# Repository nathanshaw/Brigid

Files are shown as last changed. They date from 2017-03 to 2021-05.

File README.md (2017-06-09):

Machine Orchesta
# Brigid
Solenoid Driver

Please note that for each board you much change the ARDUINO_ID to a unique number

If you want to turn off LED feedback change LED_FEEDBACK to 0

If you don't want the startup sequence change BOOT_TEST to 0

If the LED is not yellow during the BOOT_TEST change your led pins until it is.

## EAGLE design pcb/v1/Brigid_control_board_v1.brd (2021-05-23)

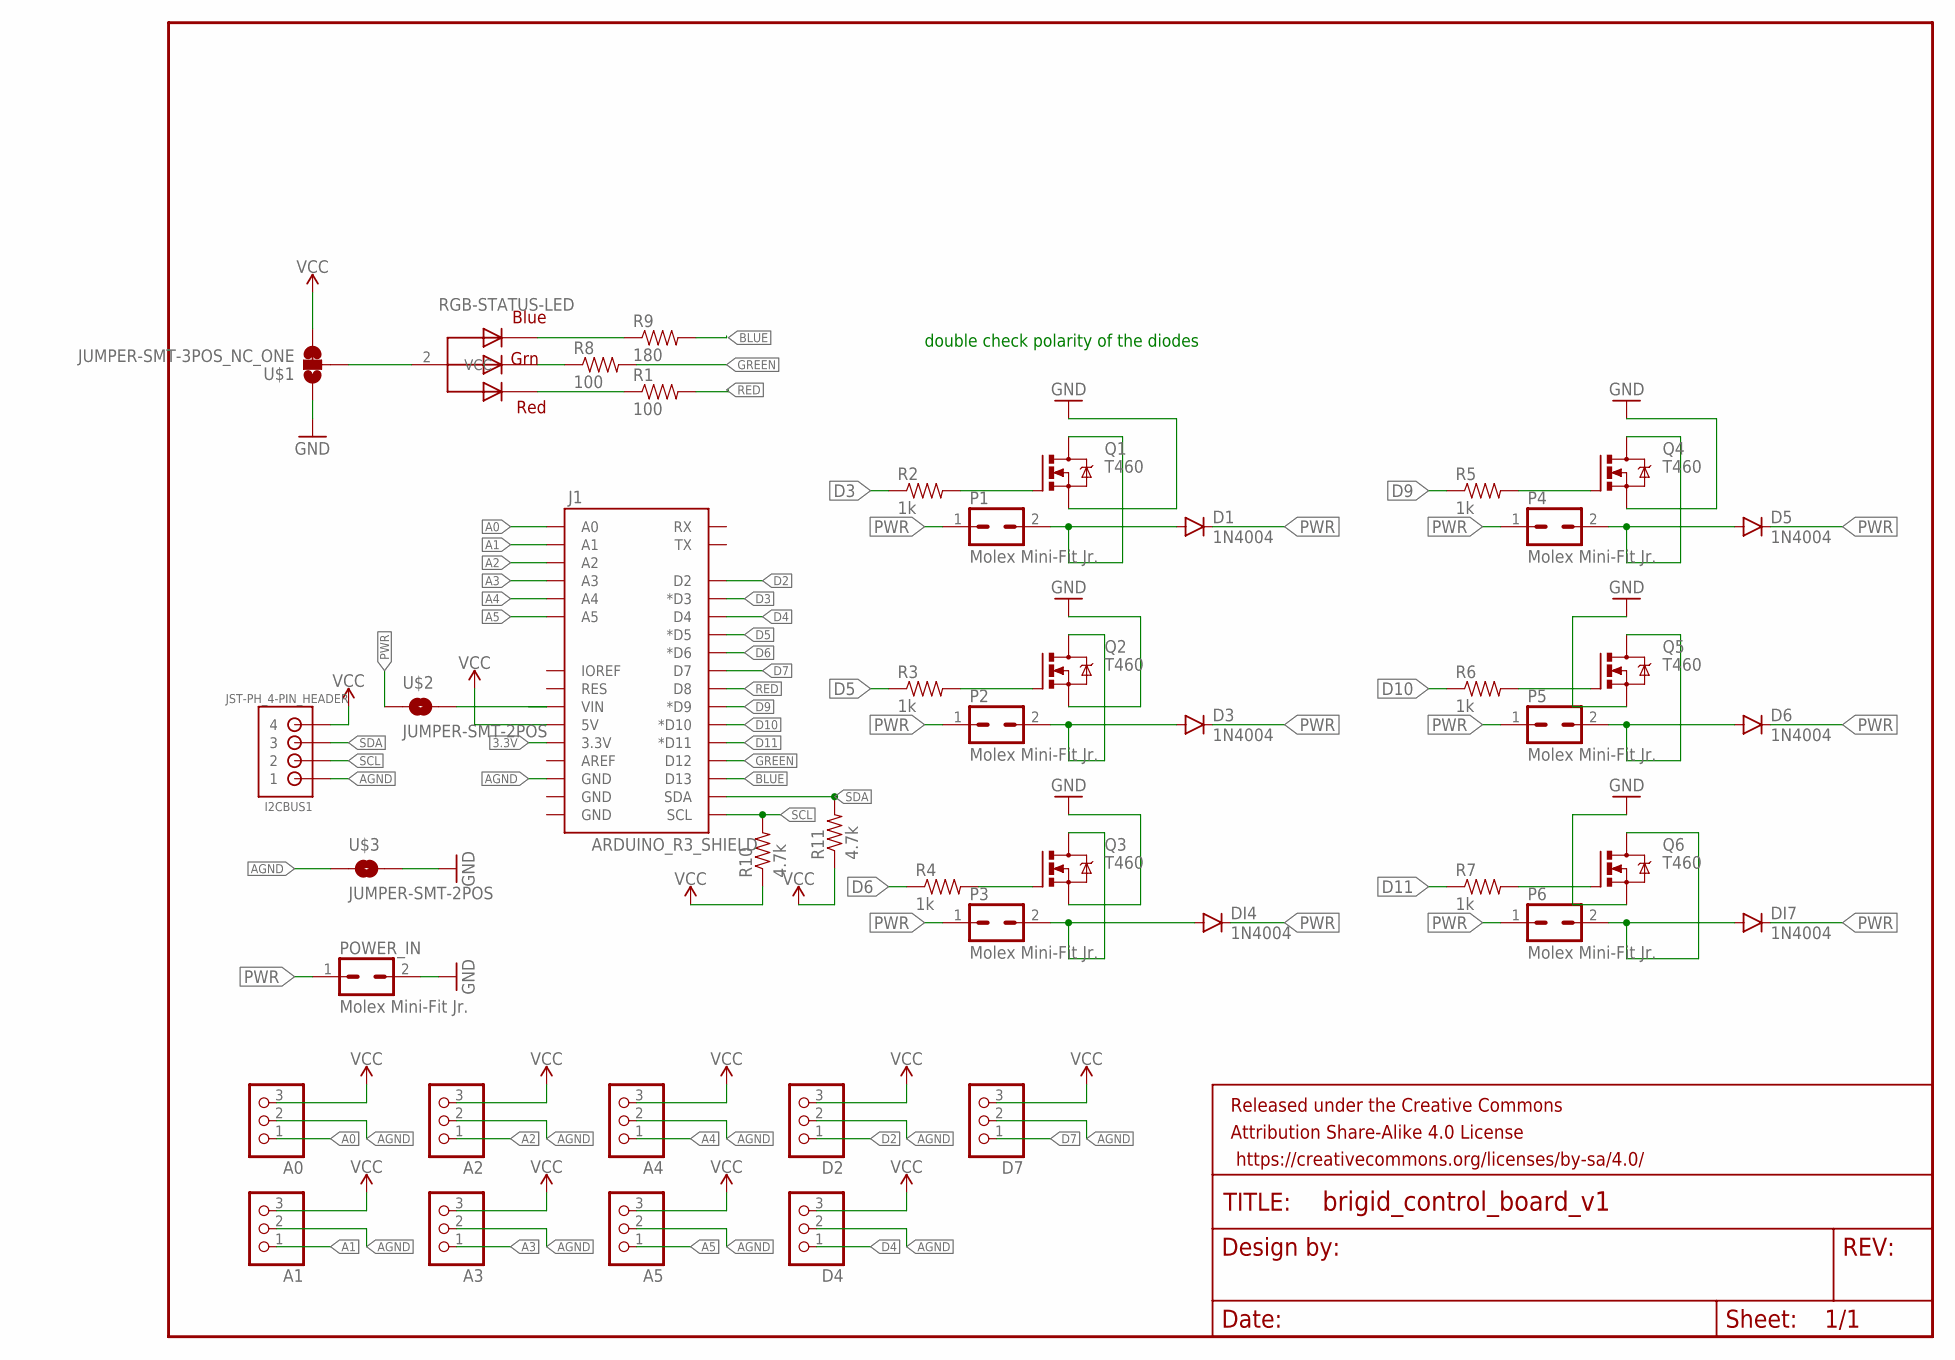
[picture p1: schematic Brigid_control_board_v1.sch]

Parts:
A0, A1, A2, A3, A4, A5: PINHD-1X3; 1X03
D1, D3, D5, D6: 1N4004; DIODE-1N4001
D2, D4, D7: PINHD-1X3; 1X03
DI4, DI7: 1N4004; DIODE-1N4001
FRAME1: FRAME-LETTER; CREATIVE_COMMONS
I2CBUS1: JST-PH_4-PIN_HEADER; JST_B4B-PH_HEADER
J1: ARDUINO_R3_SHIELD; UNO_R3_SHIELD
P1, P2, P3, P4, P5, P6: Molex Mini-Fit Jr.; 39-30-?02?
POWER_IN: Molex Mini-Fit Jr.; 39-30-?02?
Q1, Q2, Q3, Q4, Q5, Q6: T460; TO220BV
R1, R8: 100; AXIAL-0.3EZ
R2, R3, R4, R5, R6, R7: 1k; AXIAL-0.3EZ
R9: 180; AXIAL-0.3EZ
R10, R11: 4.7k; AXIAL-0.3EZ
RGB-STATUS-LED: RGB LED; LED5MMRGB
U$1: JUMPER-SMT-3POS_NC_ONE; SMT-JUMPER_3_1-NC_TRACE_NO-SILK
U$2, U$3: JUMPER-SMT-2POS; SMT-JUMPER_2_NO_NO-SILK

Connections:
3.3V: J1.3.3V
A0: A0.1, J1.A0
A1: A1.1, J1.A1
A2: A2.1, J1.A2
A3: A3.1, J1.A3
A4: A4.1, J1.A4
A5: A5.1, J1.A5
AGND: A0.2, A1.2, A2.2, A3.2, A4.2, A5.2, D2.2, D4.2, D7.2, I2CBUS1.P1 (1), J1.GND@2 (GND), U$3.1
BLUE: J1.D13, R9.P$2 (2)
D2: D2.1, J1.D2
D3: J1.D3 (*D3), R2.P$1 (1)
D4: D4.1, J1.D4
D5: J1.D5 (*D5), R3.P$1 (1)
D6: J1.D6 (*D6), R4.P$1 (1)
D7: D7.1, J1.D7
D9: J1.D9 (*D9), R5.P$1 (1)
D10: J1.D10 (*D10), R6.P$1 (1)
D11: J1.D11 (*D11), R7.P$1 (1)
GND: POWER_IN.2, Q1.S, Q2.S, Q3.S, Q4.S, Q5.S, Q6.S, U$1.1, U$3.2
GREEN: J1.D12, R8.P$2 (2)
unnamed: D1.A, P1.2, Q1.D
unnamed: R9.P$1 (1), RGB-STATUS-LED.4 (BLUE)
unnamed: RGB-STATUS-LED.2 (VCC), U$1.2
unnamed: R1.P$1 (1), RGB-STATUS-LED.1 (RED)
unnamed: R8.P$1 (1), RGB-STATUS-LED.3 (GREEN)
unnamed: Q2.G, R3.P$2 (2)
unnamed: D3.A, P2.2, Q2.D
unnamed: Q1.G, R2.P$2 (2)
unnamed: Q3.G, R4.P$2 (2)
unnamed: DI4.A, P3.2, Q3.D
unnamed: Q4.G, R5.P$2 (2)
unnamed: D5.A, P4.2, Q4.D
unnamed: Q5.G, R6.P$2 (2)
unnamed: D6.A, P5.2, Q5.D
unnamed: Q6.G, R7.P$2 (2)
unnamed: DI7.A, P6.2, Q6.D
PWR: D1.C, D3.C, D5.C, D6.C, DI4.C, DI7.C, P1.1, P2.1, P3.1, P4.1, P5.1, P6.1, POWER_IN.1, U$2.1
RED: J1.D8, R1.P$2 (2)
SCL: I2CBUS1.P2 (2), J1.SCL, R10.P$2 (2)
SDA: I2CBUS1.P3 (3), J1.SDA, R11.P$2 (2)
VCC: A0.3, A1.3, A2.3, A3.3, A4.3, A5.3, D2.3, D4.3, D7.3, I2CBUS1.P4 (4), J1.5V, R10.P$1 (1), R11.P$1 (1), U$1.3
VIN: J1.VIN, U$2.2

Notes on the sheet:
double check polarity of the diodes

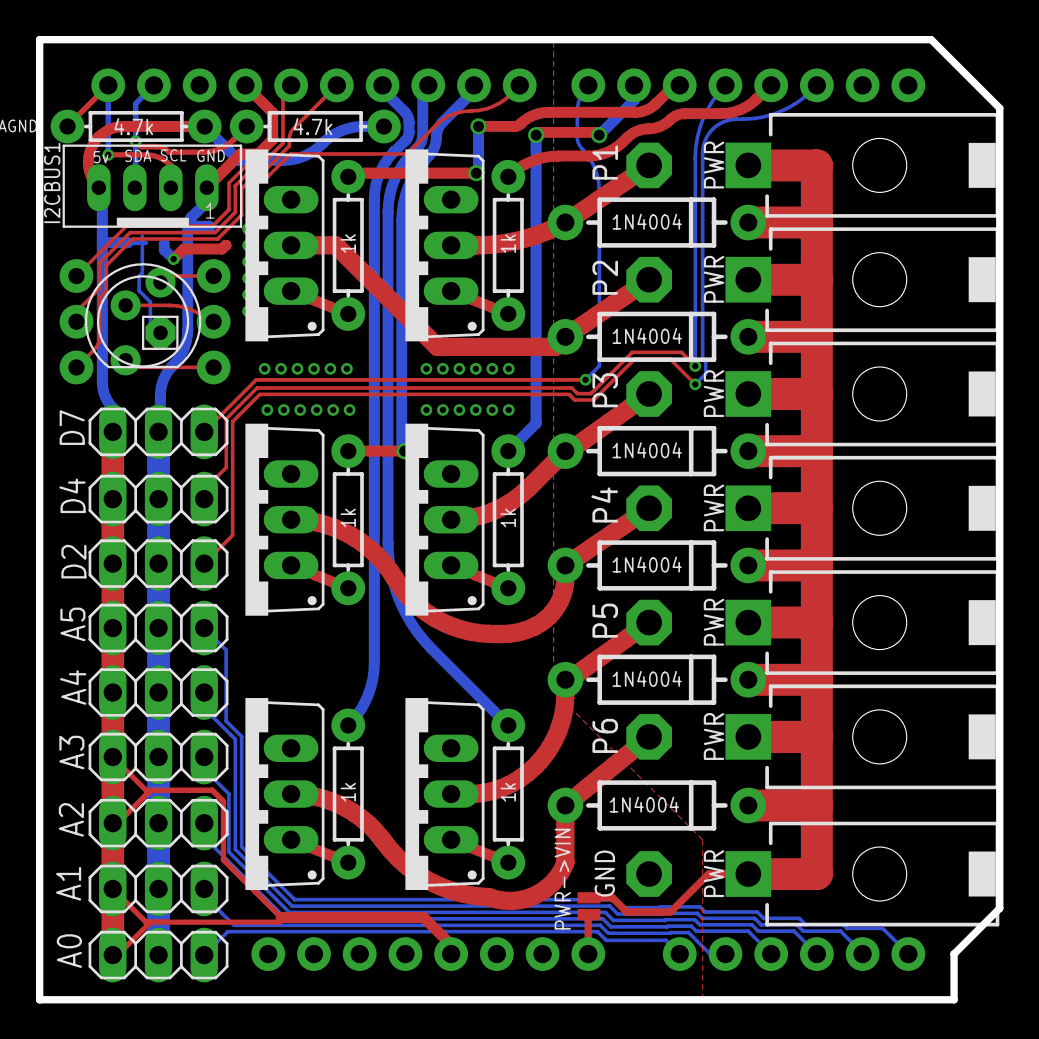
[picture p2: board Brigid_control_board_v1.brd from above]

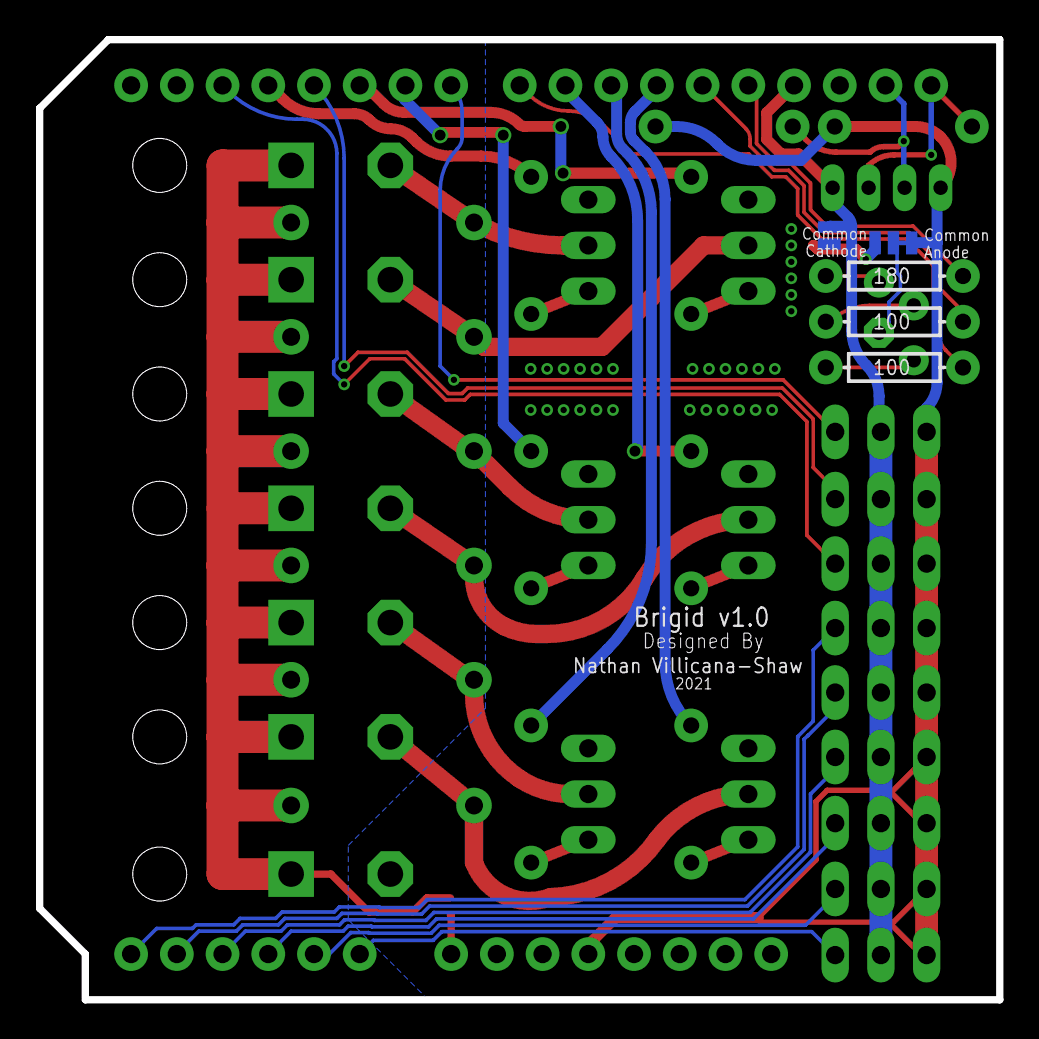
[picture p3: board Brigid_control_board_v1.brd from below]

Board: 2 copper layers, 53.3 x 53.3 mm, 46 parts (5 on the bottom side), 41 nets.

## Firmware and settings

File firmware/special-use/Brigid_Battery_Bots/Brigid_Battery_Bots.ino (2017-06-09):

// solenoids need to happen before the motors
// botnum/board type/board num

#define BOOT_TEST 1
#define LED_FEEDBACK 1
#define RED_LED A4
#define GREEN_LED A3
#define BLUE_LED A2
#define NUM_SOLENOIDS 4
#define NUM_LEDS 2
#define NUM_MOTORS 0

// actuator pins
int actuators[] = {
  3, 5, 6, 9, 10, 11
};

int motors[] = {
};

// just the solenoids
int solenoids[] = {
  3, 5, 6, 10
};
// just the leds
int leds[] = {
  11, 7
};

void setup() {
  Serial.begin(57600);
  // interrupt timer parameters
  pinMode(RED_LED, OUTPUT);
  pinMode(GREEN_LED, OUTPUT);
  pinMode(BLUE_LED, OUTPUT);
  digitalWrite(GREEN_LED, HIGH);
  digitalWrite(RED_LED, HIGH);
  digitalWrite(BLUE_LED, LOW);

  for (int i = 0; i < NUM_SOLENOIDS; i++) {
    pinMode(actuators[i], OUTPUT);
    digitalWrite(actuators[i], LOW);
  }
  for (int i = 0; i < NUM_LEDS; i++) {
    pinMode(leds[i], OUTPUT);
    digitalWrite(actuators[i], LOW);
  }
  for (int i = 0; i < NUM_MOTORS; i++) {
    pinMode(motors[i], OUTPUT);
    digitalWrite(actuators[i], LOW);
  }
  digitalWrite(GREEN_LED, LOW);
  digitalWrite(RED_LED, LOW); 
}

void allAtOnce(int delayTime){
  Serial.print("All at once : ");
  Serial.print(" : ");
  Serial.println(delayTime);
  // turn everything on at once
  for (int t = 0; t < 6; t++){
    digitalWrite(actuators[t], HIGH);
    delay(1);
  }
  delay(50);
  for (int t = 0; t < 6; t++){
    digitalWrite(actuators[t], LOW);
    delay(1);
  }
  delay(delayTime);
}

void cycleThrough(int delayTime){
  Serial.print("Cycle Through 2 ");
  Serial.print(" : ");
  Serial.println(delayTime);
  for (int i = int(delayTime*0.5); i > 2; i--) {
    for (int t = NUM_MOTORS; t < 6; t++){
      if (random() > 0.6){
        digitalWrite(actuators[t], HIGH);
        delay(i + random(10));
        digitalWrite(actuators[t], LOW);
        delay(delayTime - i);
      }
    } 
  } 
}

void allOff() {
  // turn everything off
  Serial.println("Turning everything off");
  for (int i; i < NUM_SOLENOIDS; i++) {
    digitalWrite(actuators[i], LOW);  
  } 
  for (int i; i < NUM_MOTORS; i++) {
    digitalWrite(actuators[NUM_SOLENOIDS + i], LOW);
  }
}

void slowRandomSolenoids1(int delayTime) {
  Serial.print("Slow random solenoids 1 ");
  Serial.print(" : ");
  Serial.println(delayTime);
  if (random() > 0.55){
    float theRandom = random();
    if (theRandom > 0.6 && NUM_SOLENOIDS > 3) {
      digitalWrite(actuators[0], HIGH);
    }
    else if(theRandom > 0.3 && NUM_SOLENOIDS > 1) {
      digitalWrite(actuators[1], HIGH);
    }
    else if(theRandom > 0.15 && NUM_SOLENOIDS > 2) {
      digitalWrite(actuators[2], HIGH);
    }
    else if(theRandom > 0 && NUM_SOLENOIDS > 3) {
      digitalWrite(actuators[3], HIGH);
    }
  }
  delay(40);
  allOff();
  delay(random(delayTime, delayTime*2)); 
}

void slowRandomSolenoids2(int delayTime) {
  Serial.print("Slow random solenoids 2 ");
  Serial.print(" : ");
  Serial.println(delayTime);
  if (random() > 0.55){
    float theRandom = random();
    if (theRandom > 0.6 && NUM_SOLENOIDS > 3) {
      solenoidHum(0, random(100,400));
    }
    else if(theRandom > 0.3 && NUM_SOLENOIDS > 1) {
      solenoidHum(1, random(100,400));
    }
    else if(theRandom > 0.15 && NUM_SOLENOIDS > 2) {
      solenoidHum(2, random(100,400));
    }
    else if(theRandom > 0 && NUM_SOLENOIDS > 3) {
      solenoidHum(3, random(100,400));
    }
  }
  delay(20);
  allOff();
  delay(random(delayTime*0.25, delayTime*2)); 
}

void pulseLights(int ledNum, int timeMS){
  Serial.print("Pulseing Lights ");
  Serial.print(ledNum);
  Serial.print(" : ");
  Serial.println(timeMS);
  float delayTime = timeMS / 512;
  for (int power = 0; power < 255; power++) {
    analogWrite(leds[ledNum], power); 
    delay(delayTime);
  }
  for (int power = 255; power > -1; power--) {
    analogWrite(leds[ledNum], power); 
    delay(delayTime);
  }
}

void solenoidHum(int solenoidNum, int timeMS){
  Serial.print("Pulseing solenoid ");
  Serial.print(solenoidNum);
  Serial.print(" : ");
  Serial.println(timeMS);
  float moddedTime = timeMS * (random() + 0.5);
  float delayTime = timeMS / 512;
  for (int power = 0; power < 255; power++) {
    analogWrite(solenoids[solenoidNum], power); 
    delay(delayTime);
  }
  delay(delayTime*10);
  for (int power = 255; power > -1; power--) {
    analogWrite(solenoids[solenoidNum], power); 
    delay(delayTime);
  }
}


void loop() {
  if(random(0, 100) < 2){
    for  (int l = 120; l >100; l = l - 3){
      cycleThrough(l);
    }
  }
  slowRandomSolenoids1(7000);
  if (random(0, 100) < 20) {
    pulseLights(0, random(2000, 10000));
  }
  solenoidHum(int(random(4)), random(100, 10000));
  if (random(0, 100) < 20) {
    pulseLights(0, random(2000, 10000));
  }
  slowRandomSolenoids2(7000);
}

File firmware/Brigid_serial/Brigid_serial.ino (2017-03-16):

#define NUM_SOLENOIDS 6
// botnum/board type/board num
#define BOT_ID 1
#define BOT_TYPE 1
#define ARDUINO_ID 4

// will trigger each solinoid during init
#define BOOT_TEST 1
// will flash LED's when board receives message
#define LED_FEEDBACK 1

#include <avr/interrupt.h>
#include <avr/io.h>

#define LED_POWER 12
#define LED_STATUS 13
#define RED_LED A4
#define GREEN_LED A3
#define BLUE_LED A2
// brigid is 12 and 13
// #define RED_LED 12
// #define GREEN_LED 13
// #define BLUE_LED 13

char bytes[2];
short notes[NUM_SOLENOIDS];

int handshake = 0;
int statustimer = 0;

// actuator pins
int actuators[] = {
  3, 5, 6, 9, 10, 11
};

void setup() {
  Serial.begin(57600);
  // interrupt timer parameters
  TCCR2A = 1;
  TCCR2B = 3;
  TIMSK2 = 1;
  pinMode(RED_LED, OUTPUT);
  pinMode(GREEN_LED, OUTPUT);
  pinMode(BLUE_LED, OUTPUT);
  digitalWrite(GREEN_LED, HIGH);
  digitalWrite(RED_LED, HIGH);
  digitalWrite(BLUE_LED, LOW);
  for (int i = 0; i < NUM_SOLENOIDS; i++) {
    pinMode(actuators[i], OUTPUT);
    digitalWrite(actuators[i], LOW);
  }
  if (BOOT_TEST == 1){
    for (int i; i < 6; i++) {
      notes[i] = 50;
      delay(350);
    } 
  }
}

ISR(TIMER2_OVF_vect) {
  // solenoid control
  for (int i = 0; i < NUM_SOLENOIDS; i++) {
    if (notes[i] > 0) {
      digitalWrite(actuators[i], HIGH);
      notes[i]--;
    }
    else {
      digitalWrite(actuators[i], LOW);
    }
  }
  if (statustimer > 0 && LED_FEEDBACK) {
    digitalWrite(BLUE_LED, HIGH);
    statustimer--;
  }
  else {
    digitalWrite(BLUE_LED, LOW);
  }
}

void loop() {
  if (Serial.available()) {
    if (Serial.read() == 0xff) {
      // reads in a two index array from ChucK
      Serial.readBytes(bytes, 2);
      // bit wise operations
      // ~~~~~~~~~~~~~~~~~~~
      // reads the first six bits for the note number
      // then reads the last ten bits for the note velocity
      int pitch = byte(bytes[0]) >> 2;
      int velocity = (byte(bytes[0]) << 8 | byte(bytes[1])) & 1023;
      // message required for "handshake" to occur
      // happens once per Arduino at the start of the ChucK serial code
      if (pitch == 63 && velocity == 1023 && handshake == 0) {
        Serial.write(BOT_ID);
        Serial.write(BOT_TYPE);
        Serial.write(ARDUINO_ID);
        handshake = 1;
        digitalWrite(GREEN_LED, LOW);
        digitalWrite(RED_LED, LOW); 
      }
      if (pitch >= 0 && pitch <= NUM_SOLENOIDS) {
        statustimer = 120;
        notes[pitch] = (velocity * 0.5);
      }
    }
  }
}

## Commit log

2016-11-08 adding brd and sch files to repo
    [Brigid_control_board.brd, Brigid_control_board.sch, Razz_control_board.brd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]
2016-11-14 updated brigid do over
    [Razz_control_board.brd, Razz_control_board.sch]
2016-12-06 made brigid rev 2, created LED version of code
    [Brigid_control_board.brd, Brigid_control_board.sch]
2017-02-05 moved things around a little
    [Brigid_control_board.brd, Brigid_control_board.sch]
2017-02-05 modified board to be othermill friendly
    [Brigid_control_board.brd]
2017-02-15 added firmware for DC_Motors
    [Brigid_control_board.brd, Brigid_control_board.sch]
2017-02-17 updated brigid board, removed switched that were not needed
    [Brigid_control_board.brd, Brigid_control_board.sch]
2017-03-16 got better versions of the firmware
    [Brigid_control_board.brd]
2017-06-07 some house cleaning
    [Brigid_control_board.brd]
2021-05-23 created the first v1 production version of the board
    [Brigid_control_board_v0.brd, Brigid_control_board_v0.sch, Brigid_control_board_v1.brd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]

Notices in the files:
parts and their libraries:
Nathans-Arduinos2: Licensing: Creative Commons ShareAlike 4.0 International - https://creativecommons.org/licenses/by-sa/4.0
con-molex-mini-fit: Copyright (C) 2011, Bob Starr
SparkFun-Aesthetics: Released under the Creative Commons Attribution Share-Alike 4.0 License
